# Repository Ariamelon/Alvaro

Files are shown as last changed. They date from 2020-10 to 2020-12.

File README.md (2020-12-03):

# Alvaro
 Pro Micro-compatible 32u4 Breakout Board

## Disclaimer
This board is a heavily-modified [Goldfish Rev. C](https://github.com/staticintlucas/Goldfish). While the schematic, basic layout, pinout (of course) etc is essentially the same, it uses 0603 components instead of 0402 and has some other changes.

## Key Features
* Mid-mount USB-C connector using a low-profile USB C 2.0 connector.
* Pin-compatible with the original Pro Micro.
* 5 extra pins on the bottom like the Elite-C and Goldfish.
* Exposed USB data lines on 2.54mm grid.
* Easier to solder than the Goldfish.
* Has fuse unlike Goldfish.
* On-board power LED.
* Fully hand-solderable.

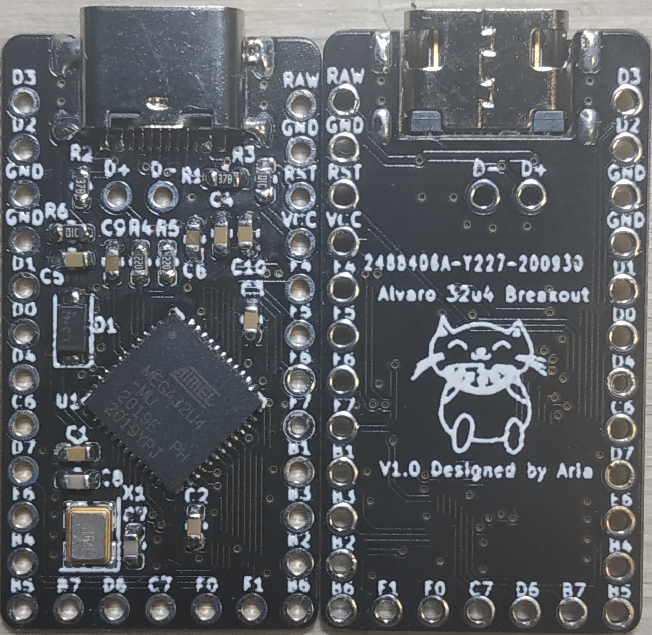
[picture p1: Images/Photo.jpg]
Alvaro Photo

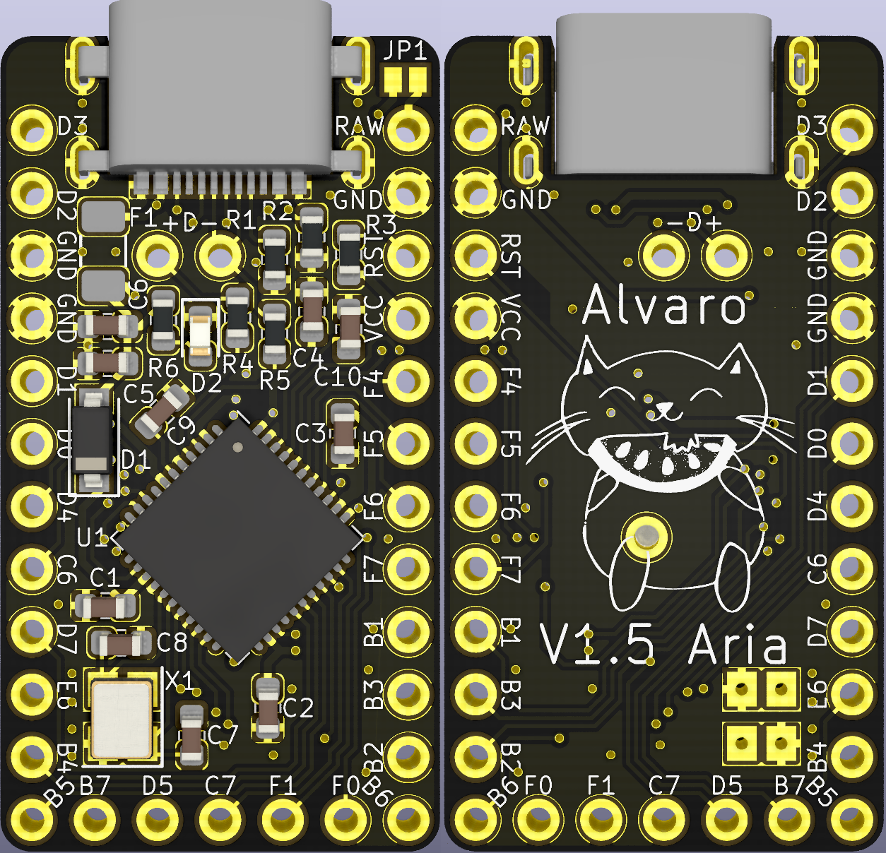
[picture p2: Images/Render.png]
Alvaro Render


## Changelog
* 27/09/2020: Initial commit.
* 29/09/2020: Switched D1 size from SOD323 to SOD123.
* 13/10/2020: Updated to V1.1. Added F1 1206 500mA polyfuse.
* 17/10/2020: Updated to V1.2. Moved location of parts closer to center.
* 31/10/2020: Updated to V1.3. Added 0603 power indicator LED, changed R6 from 10k to 1k LED resistor.
* 29/11/2020: Updated to V1.4. Increased size of 3225 crystal pads, changed USB C THT holes back to single oval shape, added THT pad under 32u4 to allow for the entire thing to be hand-soldered easier.
* 3/12/2020: Updated to V1.5. Decreased size of 3225 crystal pads again and changed them to THT. Staggered components to allow for easier soldering.

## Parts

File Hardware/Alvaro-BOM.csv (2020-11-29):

Name | Component | Package | Value | Qty
C1-C5, C10 | Capacitor | 0603 | 100nF | 6
C6 | Capacitor | 0603 | 4.7uF | 1
C7, C8 | Capacitor | 0603 | 22pF | 2
C9 | Capacitor | 0603 | 1uF | 1
D1 | Schottky | SOD-123 | <.5VF | 1
D2 | LED | 0603 | Any colour | 1
F1 | Polyfuse | 1206 | >=500mA | 1
P1 | USB C Female | C168688 |  | 1
R1, R2 | Resistor | 0603 | 5.1k | 2
R3 | Resistor | 0603 | 10k | 1
R4, R5 | Resistor | 0603 | 22R | 2
R6 | Resistor | 0603 | 1k | 1
U1 | Atmega32U4-MU(R) | QFN | - | 1
X1 | Crystal | 3225 | 16MHz | 1

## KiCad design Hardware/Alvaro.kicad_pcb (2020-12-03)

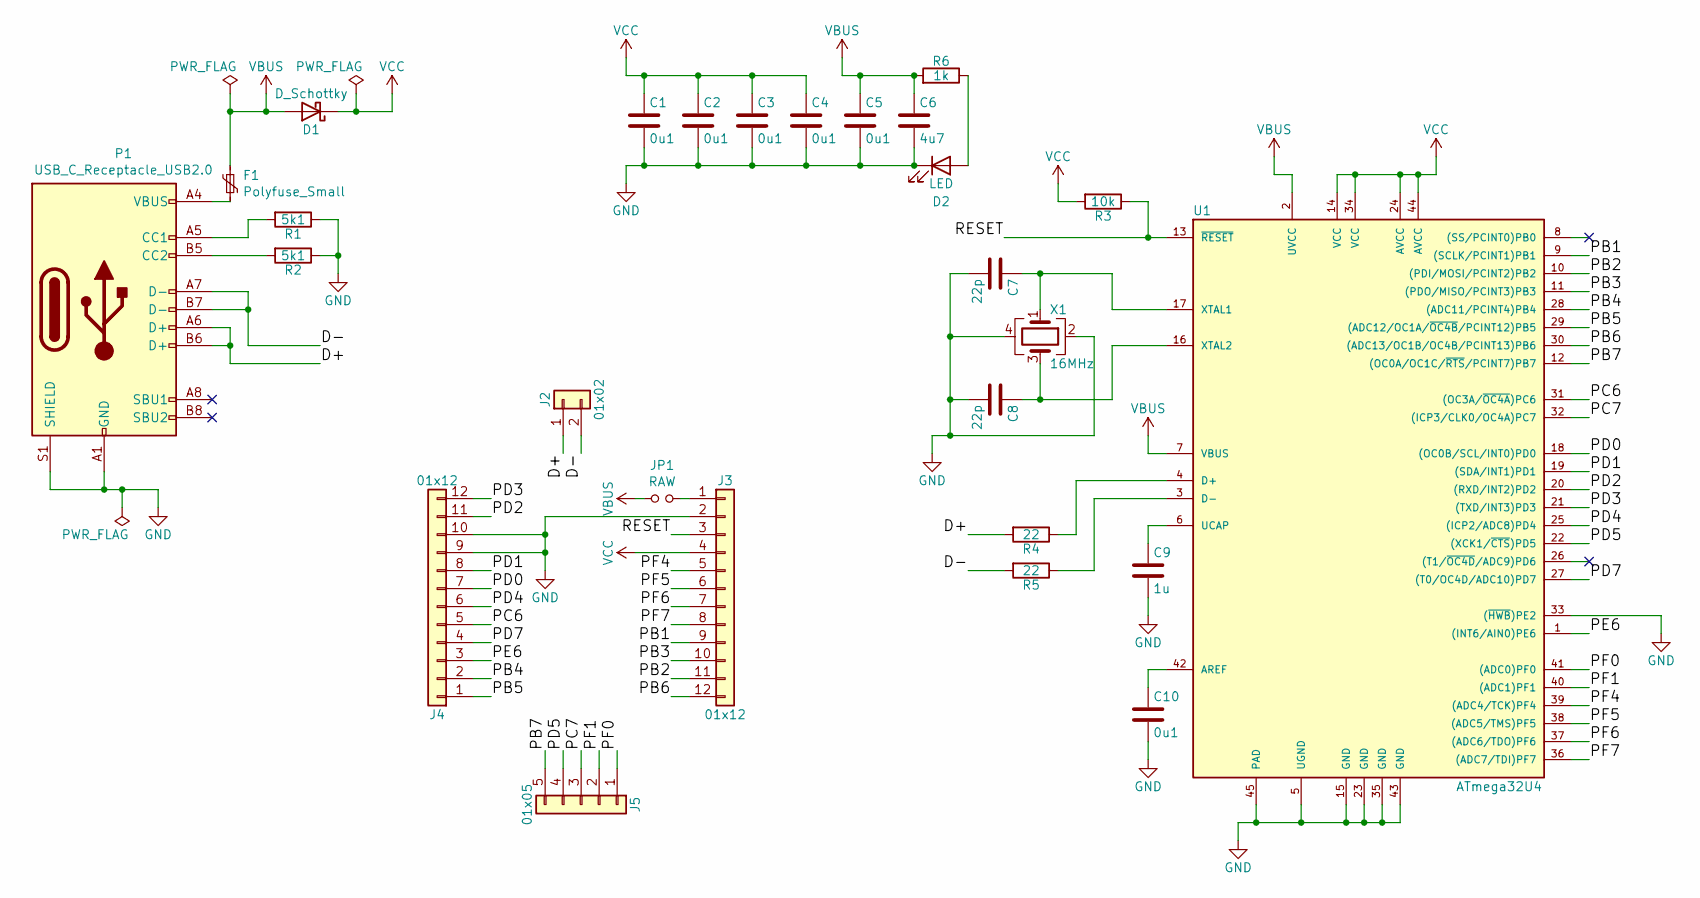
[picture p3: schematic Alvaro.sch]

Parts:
C1, C2, C3, C4, C5, C10: 0u1; C_0603_1608Metric
C6: 4u7; C_0603_1608Metric
C7, C8: 22p; C_0603_1608Metric
C9: 1u; C_0603_1608Metric
D1: D_Schottky; D_SOD-123
D2: LED; LED_0603_1608Metric
F1: Polyfuse_Small; Fuse_1206_3216Metric
J2: 01x02; Pins2
J3, J4: 01x12; Pins12
J5: 01x05; Pins5
JP1: RAW; SolderJumper-2_P1.3mm_Open_Pad1.0x1.5mm
P1: USB_C_Receptacle_USB2.0; USB-C-C168688
R1, R2: 5k1; R_0603_1608Metric
R3: 10k; R_0603_1608Metric
R4, R5: 22; R_0603_1608Metric
R6: 1k; R_0603_1608Metric
U1: ATmega32U4; QFN-44-1EP_7x7mm_P0.5mm_EP5.2x5.2mm
X1: 16MHz; Crystal_SMD_SeikoEpson_FA238-4Pin_3.2x2.5mm

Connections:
/D+: J2.1, P1.A6 (D+), P1.B6 (D+), R4.2
/D-: J2.2, P1.A7 (D-), P1.B7 (D-), R5.2
/PB1: J3.9, U1.9 ((SCLK/PCINT1)PB1)
/PB2: J3.11, U1.10 ((PDI/MOSI/PCINT2)PB2)
/PB3: J3.10, U1.11 ((PDO/MISO/PCINT3)PB3)
/PB4: J4.2, U1.28 ((ADC11/PCINT4)PB4)
/PB5: J4.1, U1.29 ((ADC12/OC1A/~OC4B~/PCINT12)PB5)
/PB6: J3.12, U1.30 ((ADC13/OC1B/OC4B/PCINT13)PB6)
/PB7: J5.5, U1.12 ((OC0A/OC1C/~RTS~/PCINT7)PB7)
/PC6: J4.5, U1.31 ((OC3A/~OC4A~)PC6)
/PC7: J5.3, U1.32 ((ICP3/CLK0/OC4A)PC7)
/PD0: J4.7, U1.18 ((OC0B/SCL/INT0)PD0)
/PD1: J4.8, U1.19 ((SDA/INT1)PD1)
/PD2: J4.11, U1.20 ((RXD/INT2)PD2)
/PD3: J4.12, U1.21 ((TXD/INT3)PD3)
/PD4: J4.6, U1.25 ((ICP2/ADC8)PD4)
/PD5: J5.4, U1.22 ((XCK1/~CTS~)PD5)
/PD7: J4.4, U1.27 ((T0/OC4D/ADC10)PD7)
/PE6: J4.3, U1.1 ((INT6/AIN0)PE6)
/PF0: J5.1, U1.41 ((ADC0)PF0)
/PF1: J5.2, U1.40 ((ADC1)PF1)
/PF4: J3.5, U1.39 ((ADC4/TCK)PF4)
/PF5: J3.6, U1.38 ((ADC5/TMS)PF5)
/PF6: J3.7, U1.37 ((ADC6/TDO)PF6)
/PF7: J3.8, U1.36 ((ADC7/TDI)PF7)
/RESET: J3.3, R3.1, U1.13 (~RESET~)
GND: C1.2, C2.2, C3.2, C4.2, C5.2, C6.2, C7.2, C8.2, C9.2, C10.2, D2.1 (K), J3.2, J4.9, J4.10, P1.A1 (GND), P1.A12 (GND), P1.B1 (GND), P1.B12 (GND), P1.S1 (SHIELD), R1.1, R2.1, U1.5 (UGND), U1.15 (GND), U1.23 (GND), U1.33 ((~HWB~)PE2), U1.35 (GND), U1.43 (GND), U1.45 (PAD), X1.2, X1.4
unnamed: C7.1, U1.17 (XTAL1), X1.1
unnamed: C8.1, U1.16 (XTAL2), X1.3
unnamed: C9.1, U1.6 (UCAP)
unnamed: C10.1, U1.42 (AREF)
unnamed: D2.2 (A), R6.1
unnamed: F1.2, P1.A4 (VBUS), P1.A9 (VBUS), P1.B4 (VBUS), P1.B9 (VBUS)
unnamed: J3.1, JP1.2
unnamed: P1.A5 (CC1), R1.2
unnamed: P1.B5 (CC2), R2.2
unnamed: R4.1, U1.4 (D+)
unnamed: R5.1, U1.3 (D-)
VBUS: C5.1, C6.1, D1.2 (A), F1.1, JP1.1, R6.2, U1.2 (UVCC), U1.7 (VBUS)
VCC: C1.1, C2.1, C3.1, C4.1, D1.1 (K), J3.4, R3.2, U1.14 (VCC), U1.24 (AVCC), U1.34 (VCC), U1.44 (AVCC)

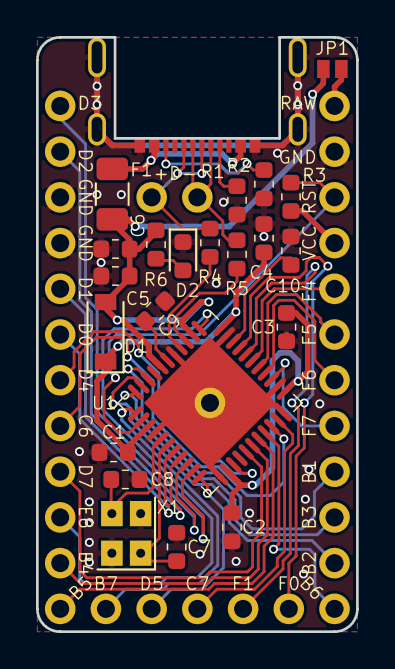
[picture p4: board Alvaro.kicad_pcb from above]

Board: 2 copper layers, 17.8 x 33.0 mm, 27 parts (0 on the bottom side), 40 nets.

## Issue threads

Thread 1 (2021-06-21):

question: BOM Details

lukeraphael, 2021-06-21:
First off, thank you for the awesome project.

Would it be possible to release a BOM for the project? I took a look at the kicad files but I'm confused about the atmega chip. When I exported the BOM, it stated that the atmega chip was the QFN package variant but from the pictures, it looks like the variant with legs would be the correct one.

Additionally, would an AU variant be useable? I believe that the only difference is that it comes with a bootloader installed. Apart from the atmega chip a BOM would be nice to double check the other components.

jettetsoi, 2021-12-08:
It should be the QFN package. I have made one.

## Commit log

2020-09-27 First upload
    [Alvaro-B_Cu.gbl, Alvaro-B_Mask.gbs, Alvaro-B_Paste.gbp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]
2020-09-28 Added Gerber files
    [Alvaro-B_Cu.gbl, Alvaro-B_Mask.gbs, Alvaro-B_Paste.gbp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]
2020-09-28 Added BOM
    [Alvaro-BOM.csv, Alvaro-BOM.xlsx]
2020-09-29 SOD323 schottky switched to SOD123
    Bigger means less heat issues
    [Alvaro-BOM.csv, Alvaro-BOM.xlsx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]
2020-10-13 Updated to V1.1
    Added 1206 500mA polyfuse to design, rerouted and moved parts, changed renders
    [Alvaro-BOM.csv, Alvaro-BOM.xlsx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]
2020-10-13 Fixed BOM
    [Alvaro-BOM.csv, Alvaro-BOM.xlsx]
2020-10-17 Fixed minor typo
    [Alvaro-BOM.csv]
2020-10-17 Updated to 1.2
    Fixed/changed silkscreen, moved parts closer to center for better compatibility with pin headers
    [Alvaro-B_Cu.gbl, Alvaro-B_Mask.gbs, Alvaro-B_Paste.gbp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]
2020-10-24 Changed location of images, changed silk a bit
    [Alvaro-B_Cu.gbl, Alvaro-B_Mask.gbs, Alvaro-B_Paste.gbp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]
2020-10-31 Updated to 1.3
    Added 0603 power indicator LED, changed R6 from 10k to 1k LED resistor.
    [Alvaro-BOM.csv, Alvaro-BOM.xlsx, Alvaro.kicad_pcb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]
2020-11-12 Fixed error
    [Alvaro-BOM.csv]
2020-11-29 Added THT pad under the 32u4.
    [Alvaro.kicad_pcb, Alvaro.sch]
2020-11-29 Revert "Added THT pad under the 32u4."
    This reverts commit 5261bc7efe342fde01f2eec8e41c6f0668064f92.
    [Alvaro.kicad_pcb, Alvaro.sch]
2020-11-29 Updated to V1.4
    [Alvaro.kicad_pcb]
2020-11-29 Revert "Updated to V1.4"
    This reverts commit e48bf29cd350433ef86578d4037b38624ab9400b.
    [Alvaro.kicad_pcb]
2020-11-29 Updated to V1.4.
    [Alvaro.kicad_pcb, Alvaro.sch]
2020-11-29 Slightly modified polyfuse spec
    [Alvaro-BOM.csv]
2020-12-03 Updated to V1.5
    [Alvaro-B_Cu.gbl, Alvaro-B_Mask.gbs, Alvaro-B_Paste.gbp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]
